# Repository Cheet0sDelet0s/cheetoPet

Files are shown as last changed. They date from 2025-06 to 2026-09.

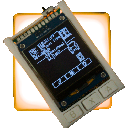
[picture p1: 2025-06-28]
photos/pixeltop.png

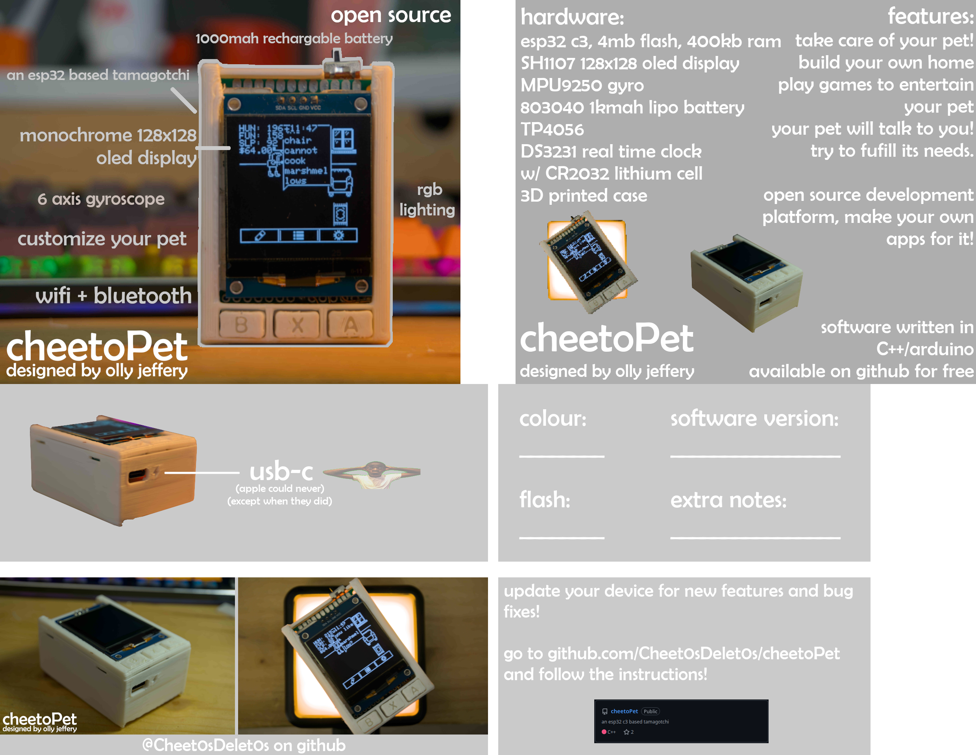
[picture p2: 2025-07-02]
photos/box.png

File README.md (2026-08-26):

<h2 align="center"><u>cheetoPet</u></h2>

**an esp32 s3 based virtual pet**
<h4 align="center"> an esp32 s3 based virtual pet </h4>

<p align="center">
    
    
<br>
    
    
</p>

### [+] notice
cheetoPet is being completely rebuilt. the pcb and software is still not finished. please star this project and come back to it later!

### [+] description
cheetoPet is a fully open-source modern tamagotchi. it features a 240*280 colour display, 3 face buttons + side rocker, 6 axis gyro and a speaker, all built on a custom pcb.

### [+] software
the software uses an abstraction layer that allows it to be ran on both esp32 and PC, where drivers for different devices can be easily created and swapped in. for PC, a lot of hardware that is present on the cheetoPet board is simulated, such as the gyro and battery. this is so the program runs as close to how it would natively. this is mostly to make development far easier, as constantly having to build the program and wait for it to upload to your esp32 takes a significant amount of time. being able to build and run it locally, while having access to regular c++ debugging tools, makes everything much less annoying.

### [+] building for pc
use the build.sh bash script in cheetoPet-V2:
`./build.sh`
you will need gcc and SDL2 installed. if the build is successful, the executable will run automatically. i develop on linux, so you may have issues if you are on windows/macos. if you are - why? without sounding like an annoying arch user (which i am), linux is simply better.

### [+] uploading to esp32
arduino IDE/CLI or the arduino vscode extension (what i use) is required to build and upload to the board. install the esp32 core in board manager, select esp32s3 dev module as your device, enable USB CDC on boot in tools and upload.

### [+] ordering pcb
i use JLCPCB for all my pcbs. they are simply the cheapest option available, but you can use any service really. just upload the gerbers and probably order a stencil to go with it. no specific board settings are needed really, though you may want to get a lower board thickness.

### [+] ordering parts
LCSC (sister company of jlcpcb)  is where i get my parts for this boardd. aliexpress unfortunately doesnt really work here. its a sad day for us all. there is a BOM you can upload however there are most likely a few parts on it that are out of stock. finding alternatives is fairly easy.

you must buy the battery and display separately. a 1S 1000mah lipo/ion is what the board expects. the display is a very specific ST7789 from BuyDisplay, you can find it on aliexpress thank GOD. https://www.aliexpress.com/item/1005008850313883.html
they are about $5-6 each.

### [+] ordering pcba
i probably wouldnt even bother assembling by hand like i did, however getting it assembled for you is just so expensive for low quantity orders. jlcpcb quoted me £150 ($200, not including battery and display cost) for 2 boards, when building 4 by hand costs £100. so unless you are ordering 1000 units, you are kind of screwed either way 🥰🥰🥰

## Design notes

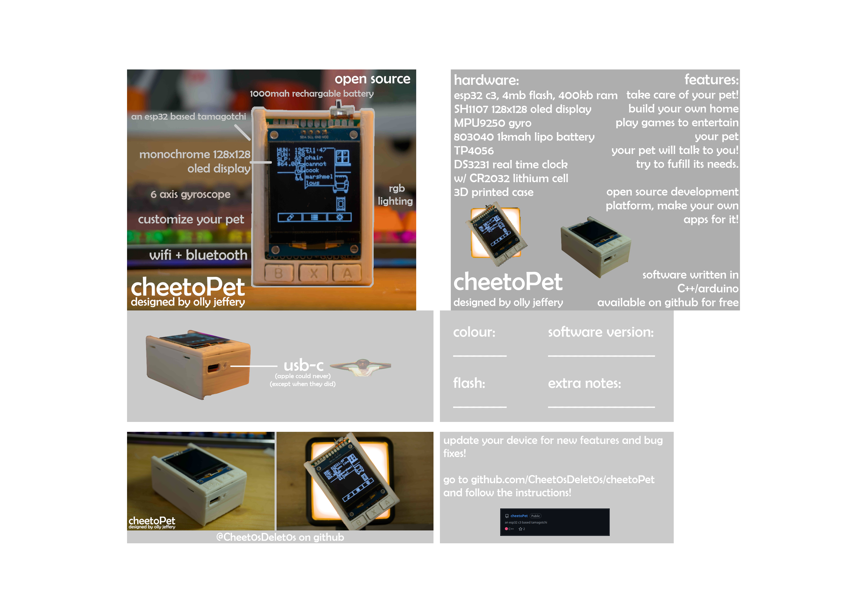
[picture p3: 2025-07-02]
photos/box2.png

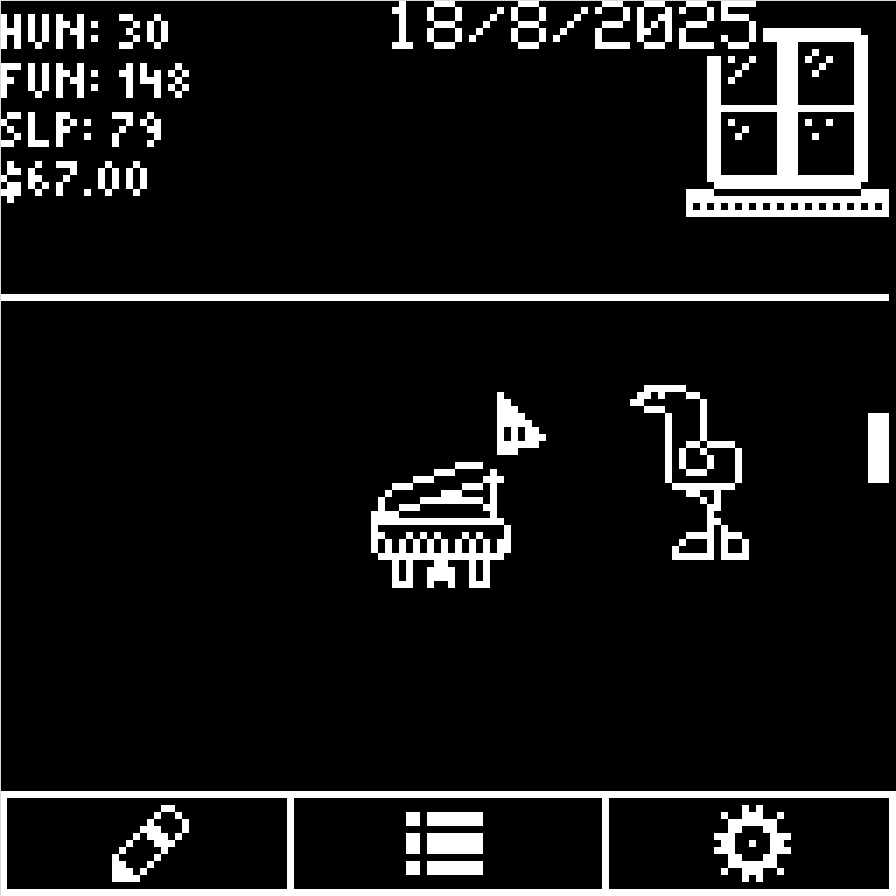
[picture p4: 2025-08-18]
photos/screenshot1.png

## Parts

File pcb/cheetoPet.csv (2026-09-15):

Reference | Qty | Value | LCSC Part Number | Exclude from BOM | Footprint
BUZZER1 | 1 | CPT-9019A-SMT-TR | C20181991 |  | EasyEDA:BUZ-SMD_L9.0-W9.0_CPT-9019A-SMT-TR
C1,C5,C6,C7,C15,C16,C17,C18,C19,C21,C24,C25,C26,C29,C31,C32,C33 | 17 | 100nF | C5137467 |  | customs:C_0805_2012Metric - CUSTOM TEXT
C2,C3,C8,C9,C20 | 5 | 10uF | C15850 |  | customs:C_0805_2012Metric - CUSTOM TEXT
C4,C30 | 2 | 1uF | C28323 |  | customs:C_0805_2012Metric - CUSTOM TEXT
C10,C14,C22,C23,C27,C28 | 6 | 22uF | C98190 |  | customs:C_0805_2012Metric - CUSTOM TEXT
CN2 | 1 | S2B-ZR-SM2-TF | C594994 |  | EasyEDA:CONN-SMD_2P-P1.50_S2B-ZR-SM2-TF-LF-SN
F1 | 1 | 1A | C2649901 |  | Fuse:Fuse_1812_4532Metric
H1,H2 | 2 | HX PZ2.54-1X5P WT | C46061678 |  | EasyEDA:HDR-SMD_5P-P2.54-H-M-W12.8-N
J2 | 1 | USB_C_Receptacle_USB2.0_16P | C2988369 |  | Connector_USB:USB_C_Receptacle_G-Switch_GT-USB-7010ASV
L1 | 1 | 0.47uH <30mOhm >4A | C42455362 |  | EasyEDA:L1008
Q1 | 1 | FS8205A | C908265 |  | footprints:SOT-23-6L_TCP
Q2 | 1 | BSS138 | C7420339 |  | Package_TO_SOT_SMD:SOT-23
R1 | 1 | 100R | C105577 |  | customs:R_0805_2012Metric - CUSTOM TEXT
R2 | 1 | 1k | C2907232 |  | customs:R_0805_2012Metric - CUSTOM TEXT
R3,R4 | 2 | 5k1 | C27834 |  | customs:R_0805_2012Metric - CUSTOM TEXT
R5,R8,R12,R15,R16,R17,R18,R22,R23,R24,R25,R26,R27,R31,R32,R35,R38 | 17 | 10k | C2907219 |  | customs:R_0805_2012Metric - CUSTOM TEXT
R7 | 1 | 1k5 | C2907216 |  | customs:R_0805_2012Metric - CUSTOM TEXT
R9 | 1 | 1k1 | C2933286 |  | customs:R_0805_2012Metric - CUSTOM TEXT
R10 | 1 | 2.94k | C865383 |  | customs:R_0805_2012Metric - CUSTOM TEXT
R11 | 1 | 18k | C17506 |  | customs:R_0805_2012Metric - CUSTOM TEXT
R19,R20 | 2 | 4k7 | C2907264 |  | customs:R_0805_2012Metric - CUSTOM TEXT
R21 | 1 | 10 | C2907220 |  | customs:R_0805_2012Metric - CUSTOM TEXT
R28,R29,R30,R33,R34,R39,R40 | 7 | 22 | C2907310 |  | customs:R_0805_2012Metric - CUSTOM TEXT
R36 | 1 | 511k | C5159719 |  | customs:R_0805_2012Metric - CUSTOM TEXT
R37 | 1 | 91k | C2933509 |  | customs:R_0805_2012Metric - CUSTOM TEXT
SW1,SW2,SW3,SW4 | 4 | BTN | C221692 |  | EasyEDA:KEY-SMD_4P-L4.2-W2.8-P1.60-LS4.6
SW5 | 1 | TS24CA | C393942 |  | EasyEDA:SW-SMD_2P-TS24CA
U1 | 1 | USBLC6-2SC6 | C5180249 |  | Package_TO_SOT_SMD:SOT-23-6
U2 | 1 | HX PM2.54-1X5P WT | C46061769 |  | EasyEDA:HDR-SMD_5P-P2.54-H-F
U3 | 1 | DW01A | C42380662 |  | Package_TO_SOT_SMD:SOT-23-6
U4 | 1 | BQ24074RGT | C54313 |  | Package_DFN_QFN:VQFN-16-1EP_3x3mm_P0.5mm_EP1.6x1.6mm
U5 | 1 | MAX17048G_T10 | C2682616 |  | Package_DFN_QFN:TDFN-8-1EP_2x2mm_P0.5mm_EP0.8x1.2mm
U6 | 1 | LSM6DSL | C126672 |  | Package_LGA:LGA-14_3x2.5mm_P0.5mm_LayoutBorder3x4y
U7 | 1 | PCF8523T/1,118 | C2651516 |  | EasyEDA:SOP-8_L4.9-W3.9-P1.27-LS6.0-BL
U8 | 1 | ESP32-S3-MINI-1U | C2980299 |  | RF_Module:ESP32-S2-MINI-1U
U9 | 1 | WS-003DB | C46598198 |  | EasyEDA:SW-SMD_WS-003DB
U10 | 1 | TPS63802DLAR | C2845237 |  | EasyEDA:VSON-10_L3.0-W2.0-P0.50-TL
U11,U13,U14 | 3 | AT24C32M/TR | C2688466 |  | EasyEDA:SOP-8_L4.9-W3.9-P1.27-LS6.0-BL
U12 | 1 | LTC2955CDDB-1#TRPBF | C683788 |  | EasyEDA:DFN-10_L3.0-W2.0-P0.50-BL-EP
X1 | 1 | SC-32S32.768kHz20PPM7pF | C97604 |  | EasyEDA:OSC-SMD_L3.2-W1.5

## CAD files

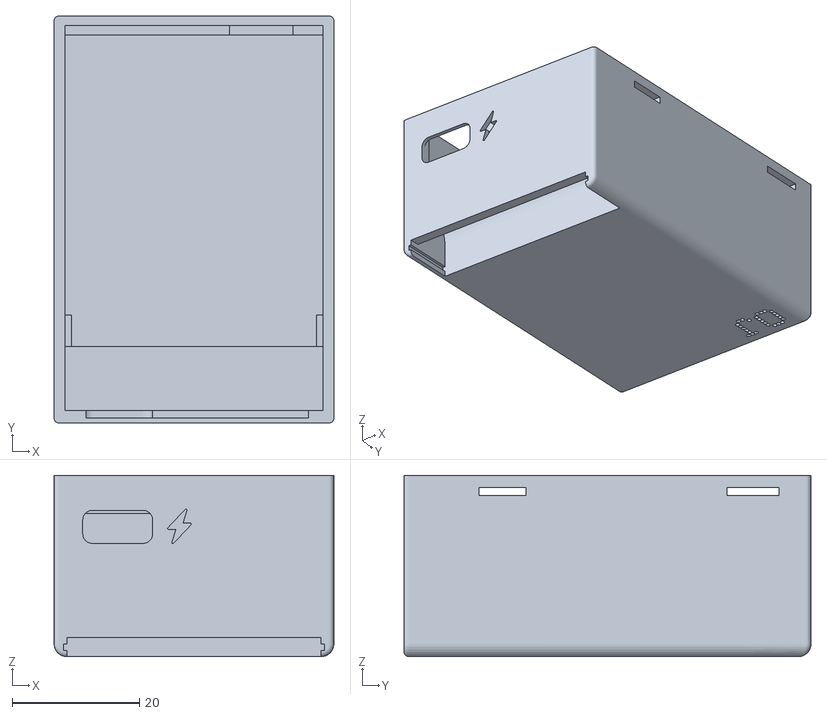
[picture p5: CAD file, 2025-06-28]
stls/body.stl
44.0 x 64.0 x 28.5

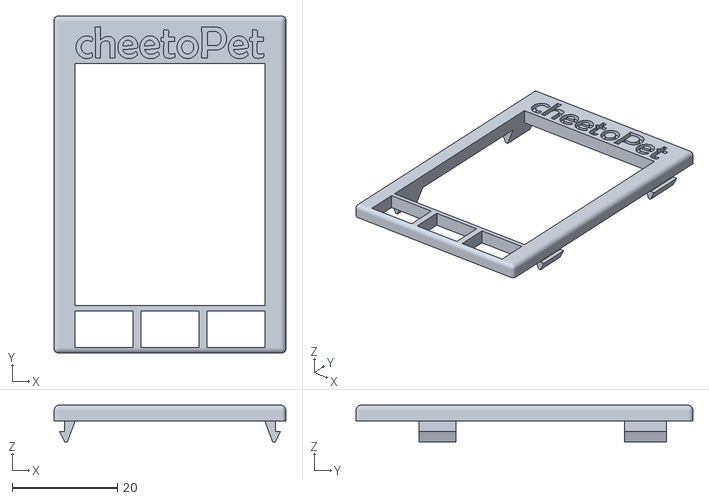
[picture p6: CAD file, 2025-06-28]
stls/faceplate.stl
44.0 x 64.0 x 7.00

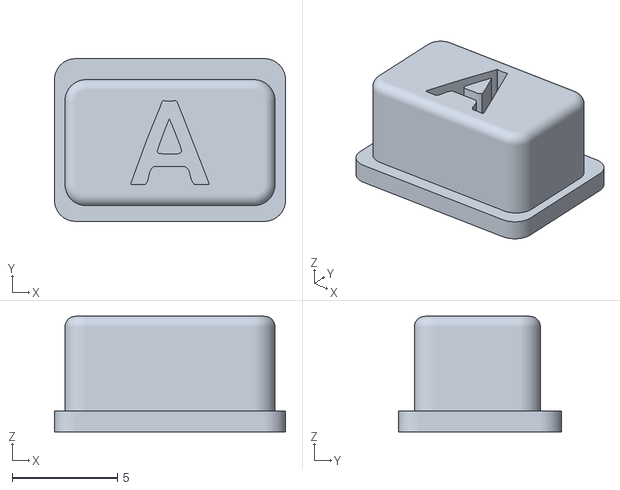
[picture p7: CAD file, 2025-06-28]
stls/A.stl
11.0 x 7.75 x 5.50

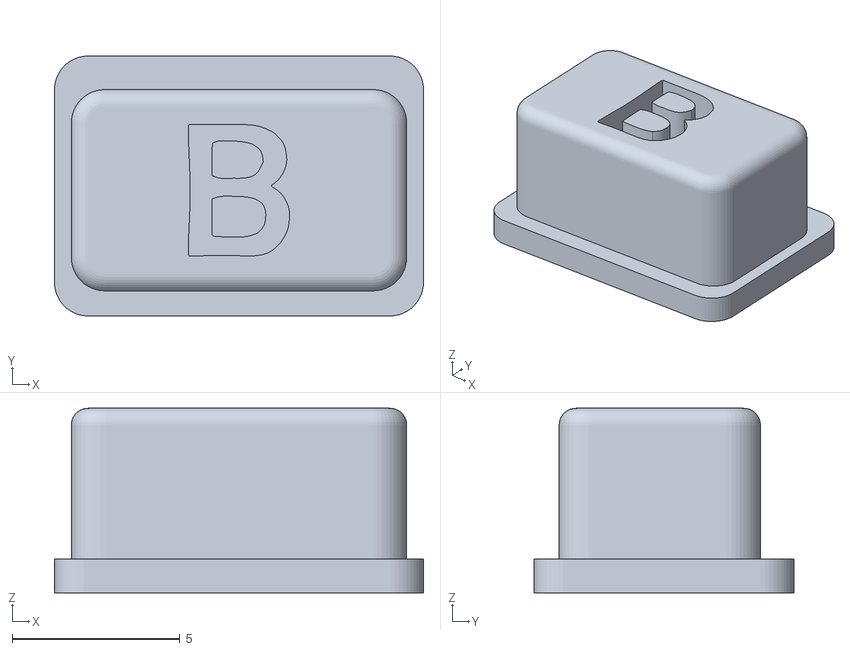
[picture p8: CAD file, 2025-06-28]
stls/B.stl
11.0 x 7.75 x 5.50

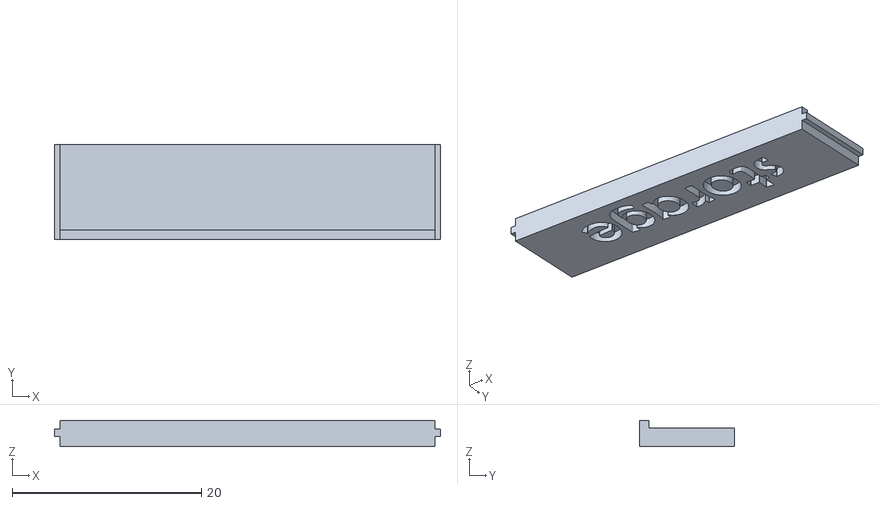
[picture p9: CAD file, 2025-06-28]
stls/manual plate.stl
40.8 x 10.0 x 2.80

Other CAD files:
stls/X.stl
legacy/stls/X.stl

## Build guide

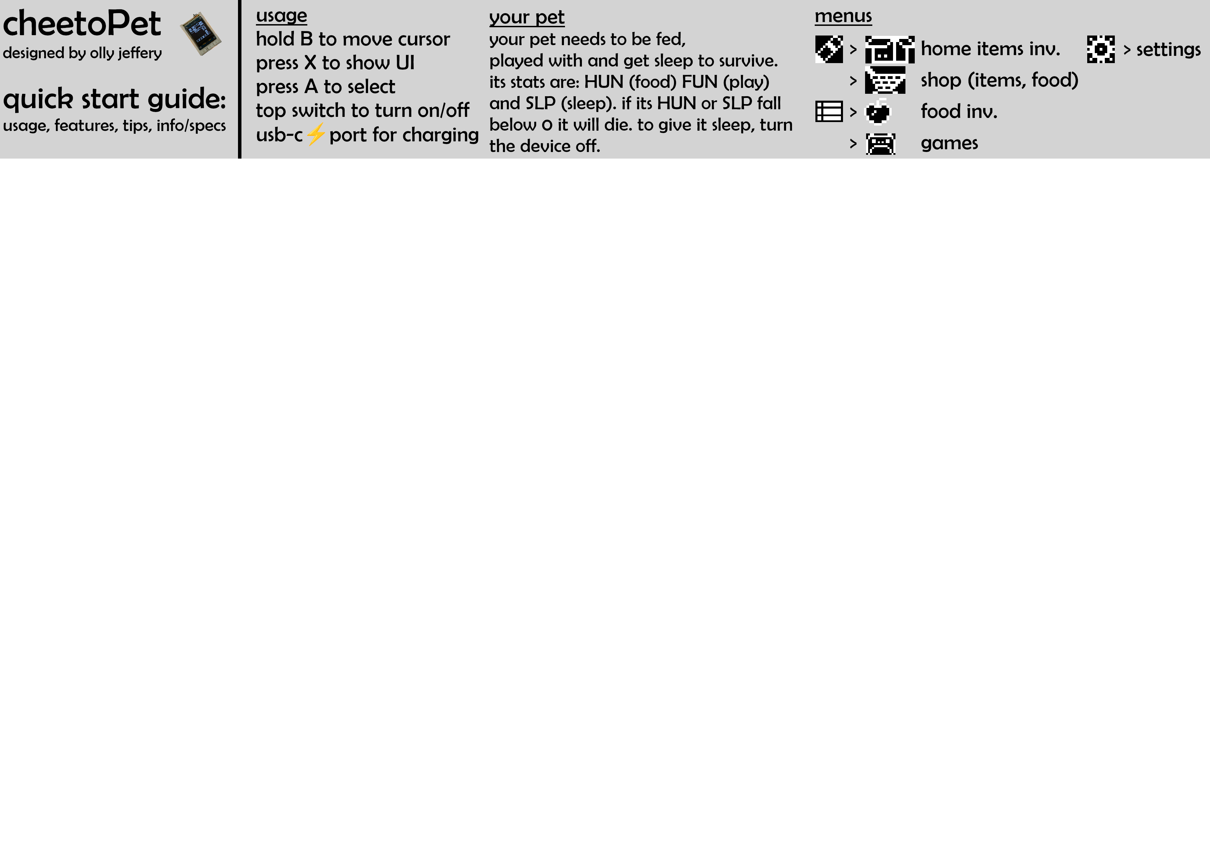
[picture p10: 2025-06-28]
photos/quick start guide.png

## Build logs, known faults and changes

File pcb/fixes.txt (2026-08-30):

FIXES NEEDED FOR PCB:

X button pulls the pin low, it should pull it high - DONE
vias under esp32 chip should probably be moved away to improve durability

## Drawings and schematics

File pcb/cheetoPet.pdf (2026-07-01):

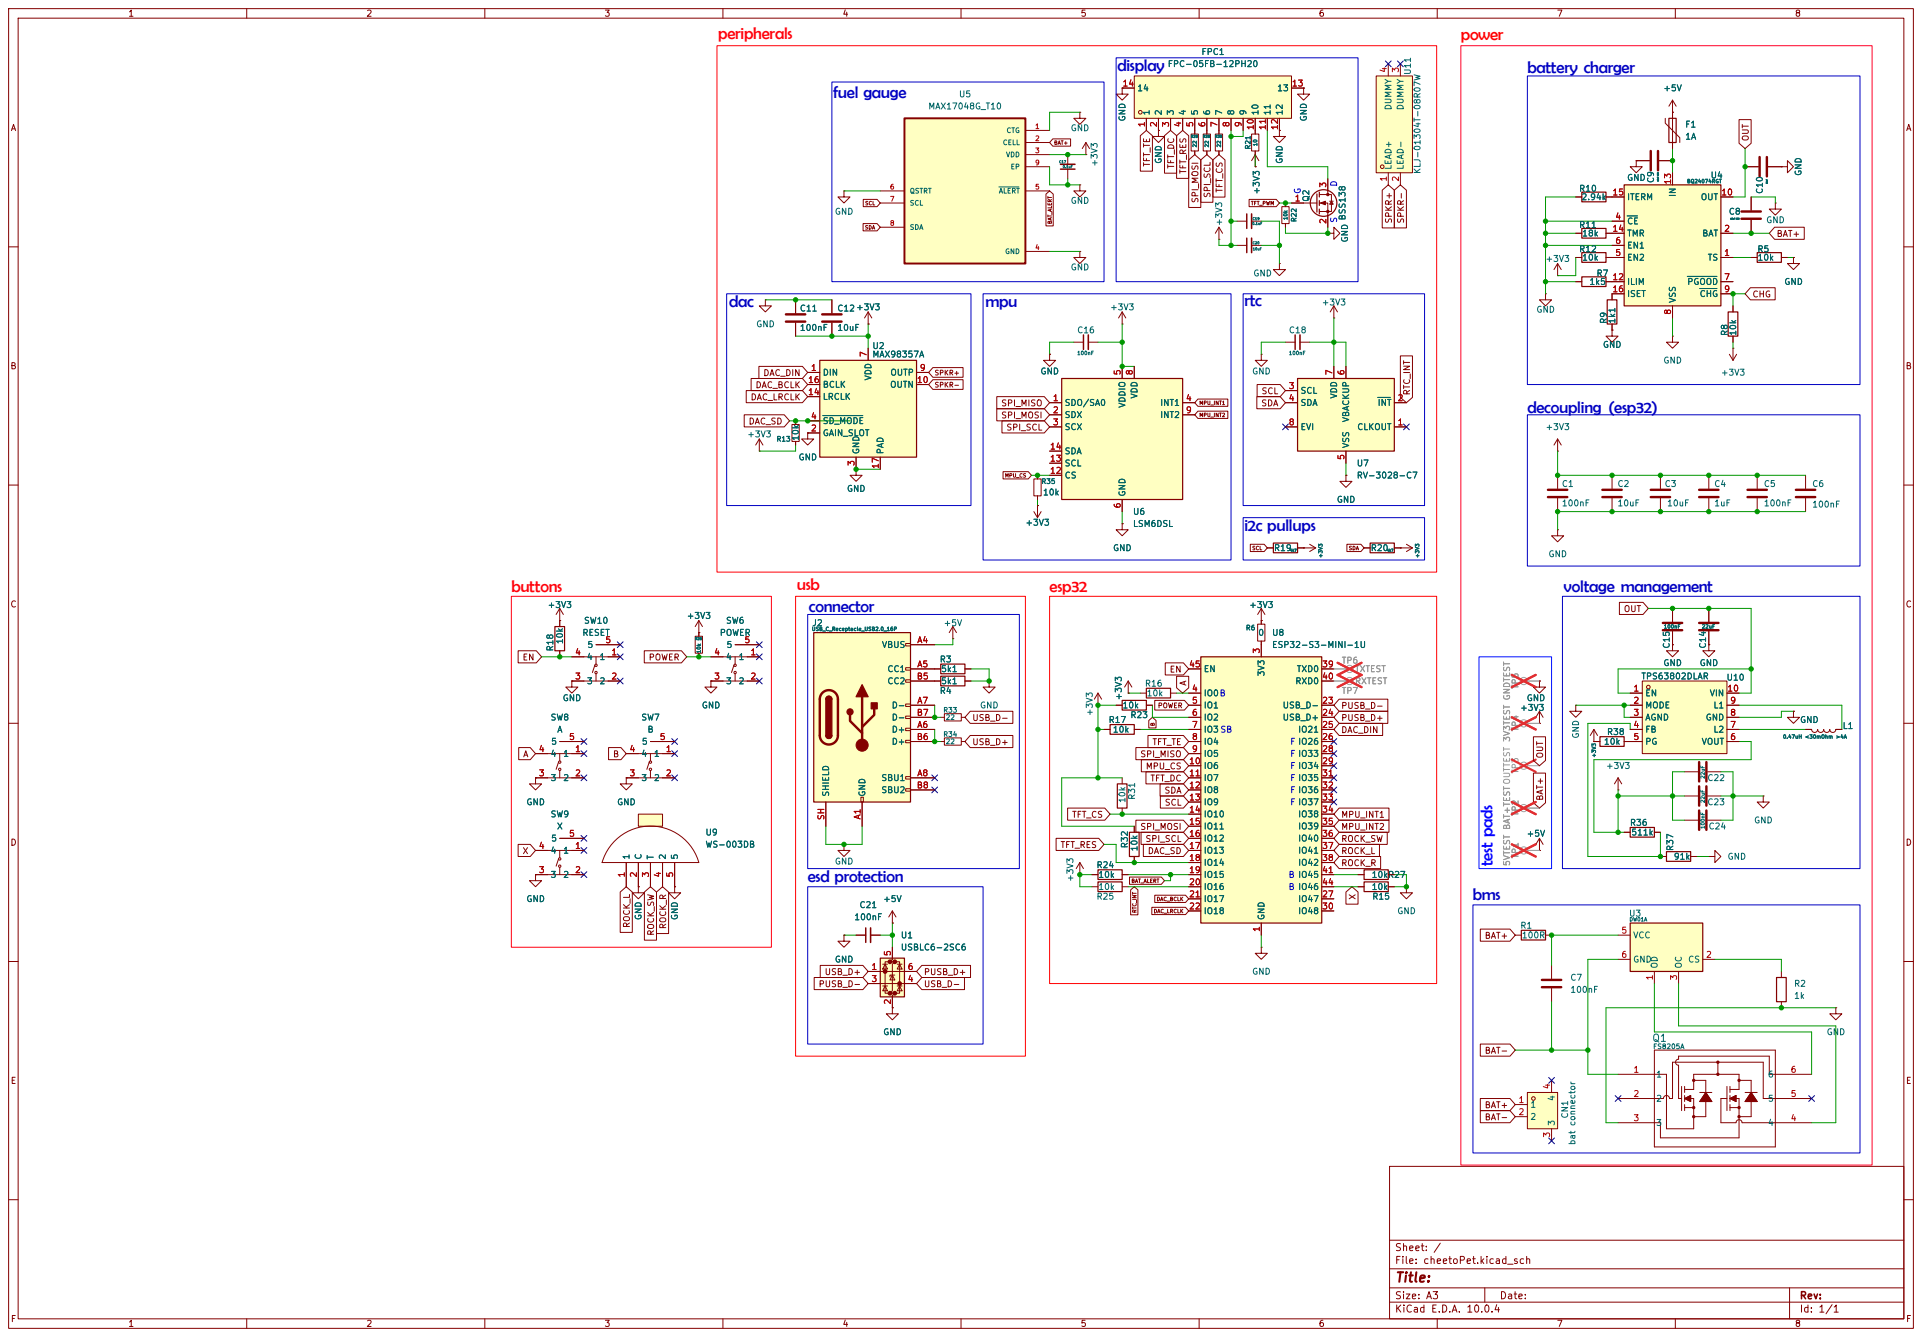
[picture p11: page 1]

TMR 14

Size: A3 | Rev:
KiCad E.D.A. 10.0.4 | Id: 1/1

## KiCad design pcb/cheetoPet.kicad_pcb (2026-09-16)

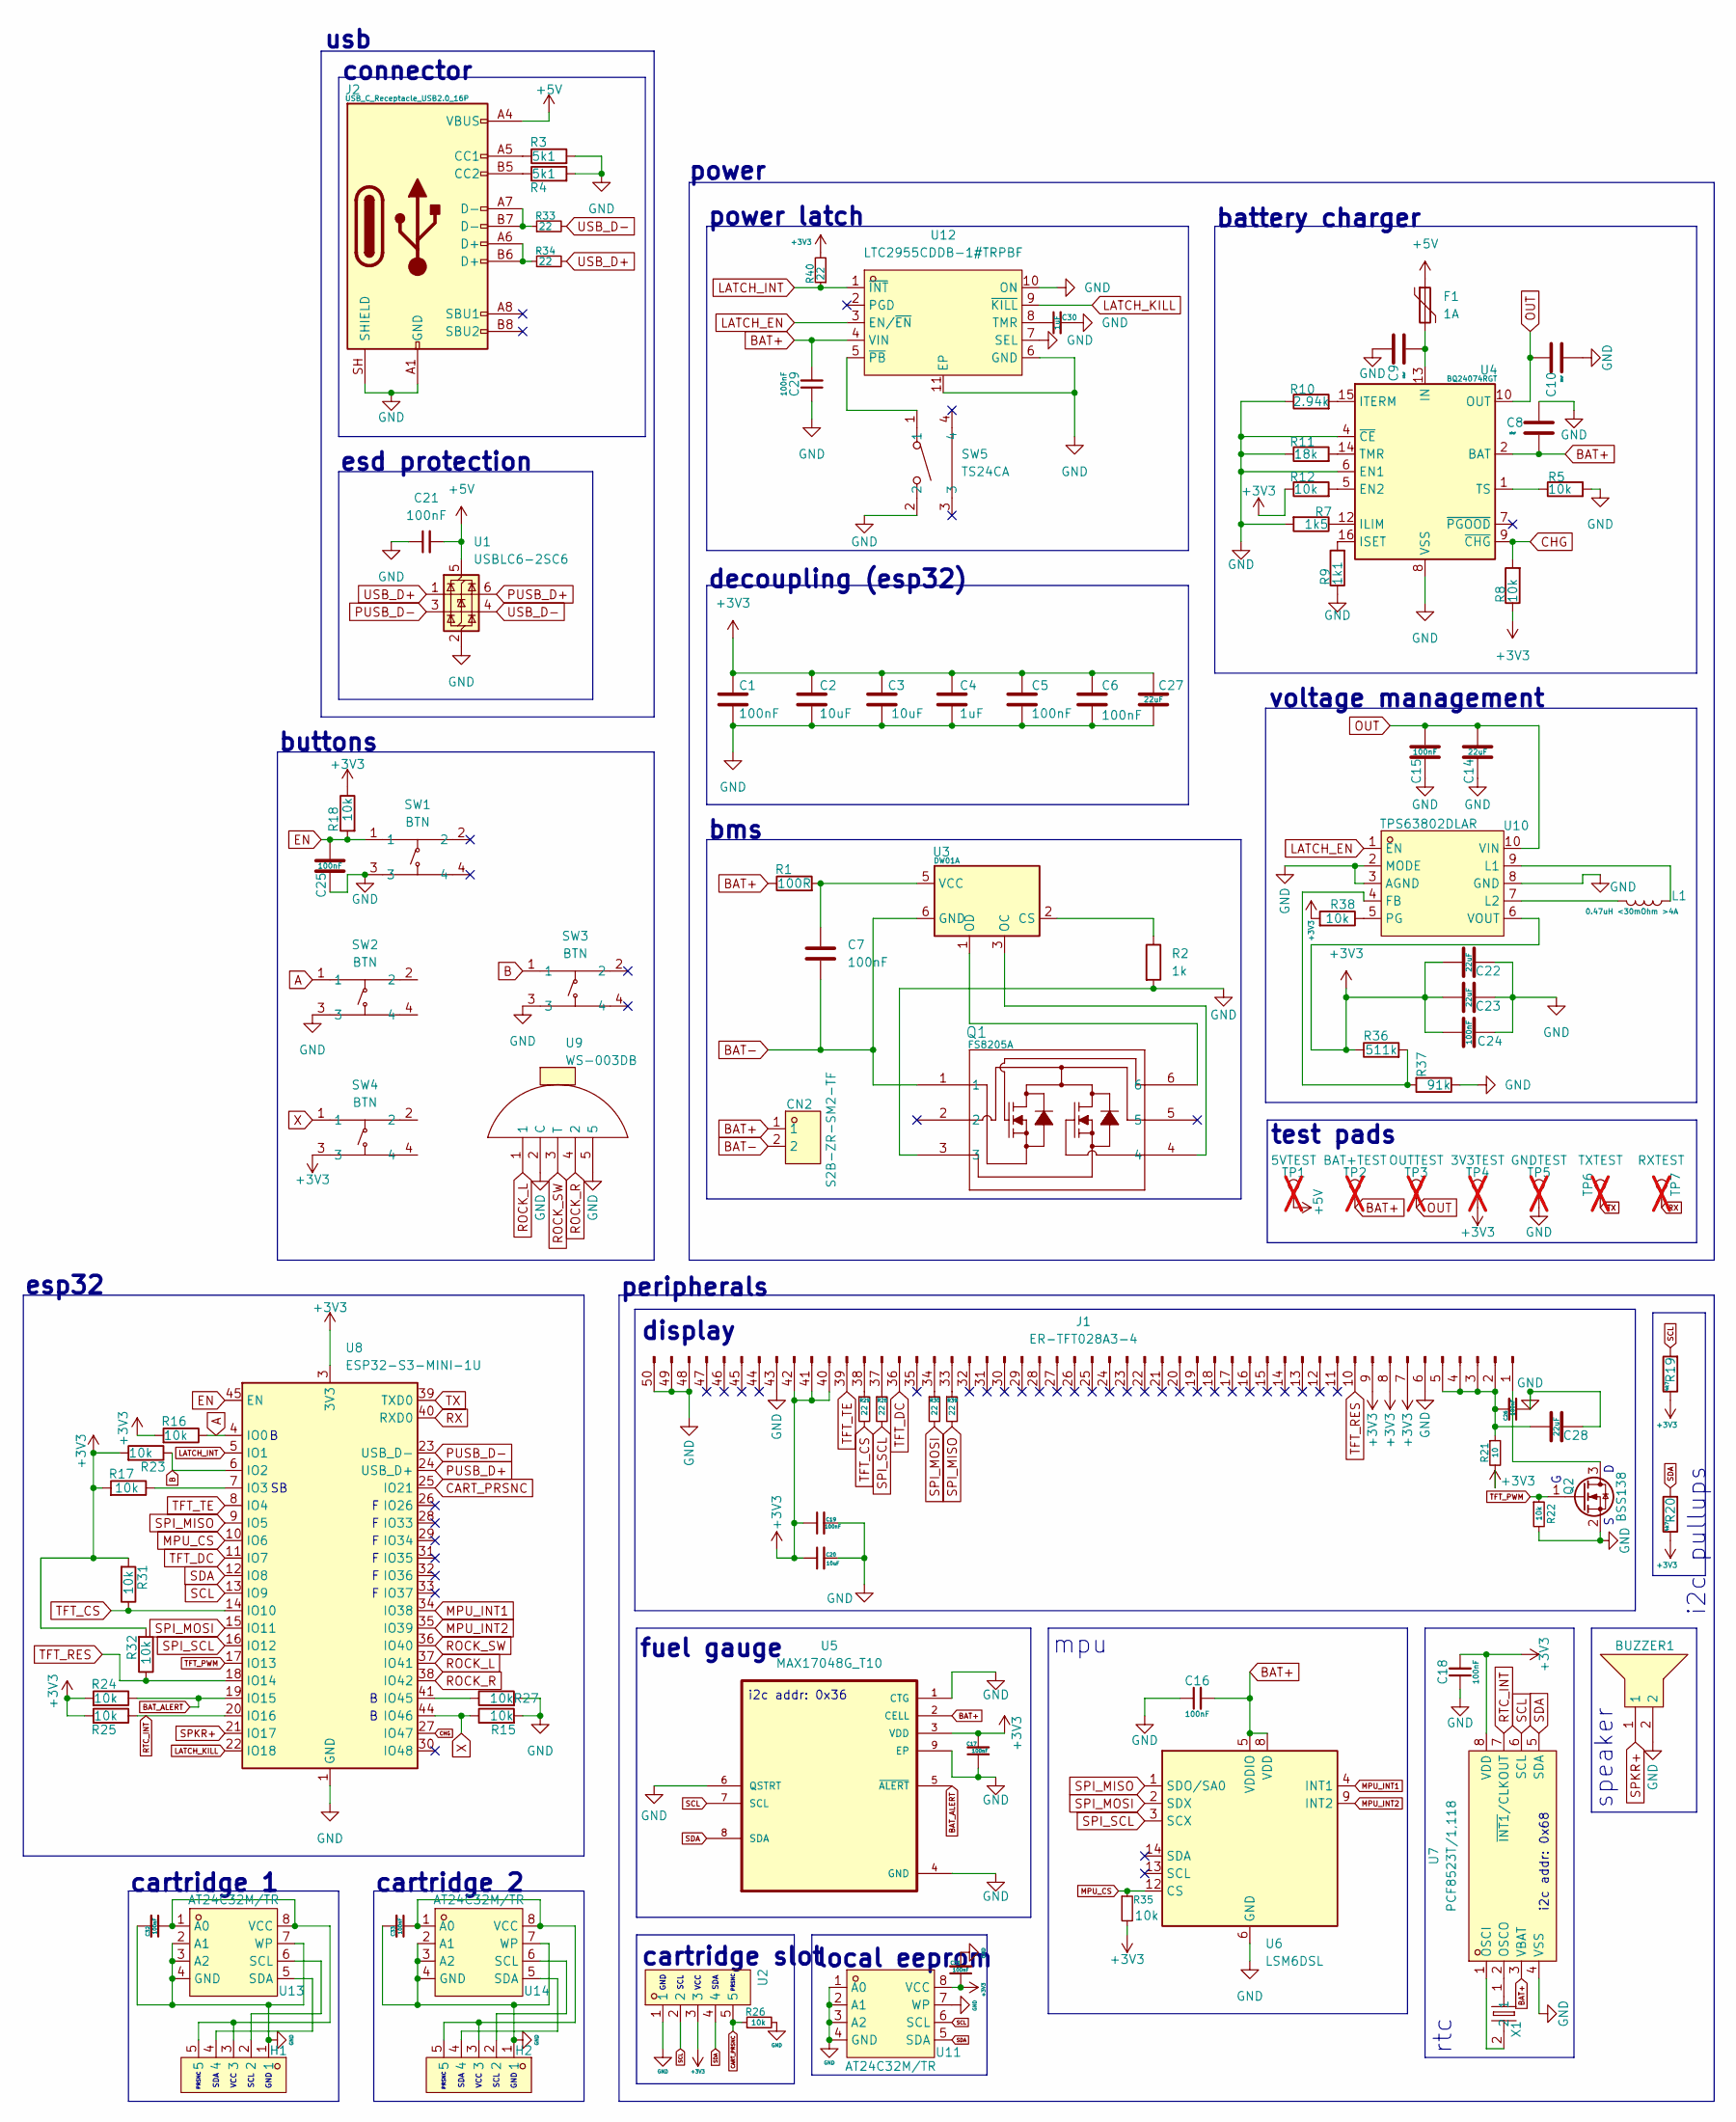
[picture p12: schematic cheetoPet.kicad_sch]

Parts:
BUZZER1: CPT-9019A-SMT-TR; BUZ-SMD_L9.0-W9.0_CPT-9019A-SMT-TR; MPN CPT-9019A-SMT-TR; LCSC Part C20181991
C1, C5, C6, C7, C15, C16, C17, C18, C19, C21, C24, C25, C26, C29, C31, C32, C33: 100nF; C_0805_2012Metric - CUSTOM TEXT; LCSC Part C5137467
C2, C3, C8, C9, C20: 10uF; C_0805_2012Metric - CUSTOM TEXT; LCSC Part C15850
C4, C30: 1uF; C_0805_2012Metric - CUSTOM TEXT; LCSC Part C28323
C10, C14, C22, C23, C27, C28: 22uF; C_0805_2012Metric - CUSTOM TEXT; LCSC Part C98190
CN2: S2B-ZR-SM2-TF; CONN-SMD_2P-P1.50_S2B-ZR-SM2-TF-LF-SN; MPN S2B-ZR-SM2-TF(LF)(SN); LCSC Part C594994
F1: 1A; Fuse_1812_4532Metric; LCSC Part C2649901
H1, H2: HX PZ2.54-1X5P WT; HDR-SMD_5P-P2.54-H-M-W12.8-N; MPN HX PZ2.54-1x5P WT; LCSC Part C46061678
J1: ER-TFT028A3-4; FPC-50pin,0.5Pitch
J2: USB_C_Receptacle_USB2.0_16P; USB_C_Receptacle_G-Switch_GT-USB-7010ASV; LCSC Part C2988369
L1: 0.47uH <30mOhm >4A; L1008; LCSC Part C42455362
Q1: FS8205A; SOT-23-6L_TCP; LCSC Part C908265
Q2: BSS138; SOT-23; LCSC Part C7420339
R1: 100R; R_0805_2012Metric - CUSTOM TEXT; LCSC Part C105577
R2: 1k; R_0805_2012Metric - CUSTOM TEXT; LCSC Part C2907232
R3, R4: 5k1; R_0805_2012Metric - CUSTOM TEXT; LCSC Part C27834
R5, R8, R12, R15, R16, R17, R18, R22, R23, R24, R25, R26, R27, R31, R32, R35, R38: 10k; R_0805_2012Metric - CUSTOM TEXT; LCSC Part C2907219
R7: 1k5; R_0805_2012Metric - CUSTOM TEXT; LCSC Part C2907216
R9: 1k1; R_0805_2012Metric - CUSTOM TEXT; LCSC Part C2933286
R10: 2.94k; R_0805_2012Metric - CUSTOM TEXT; LCSC Part C865383
R11: 18k; R_0805_2012Metric - CUSTOM TEXT; LCSC Part C17506
R19, R20: 4k7; R_0805_2012Metric - CUSTOM TEXT; LCSC Part C2907264
R21: 10; R_0805_2012Metric - CUSTOM TEXT; LCSC Part C2907220
R28, R29, R30, R33, R34, R39, R40: 22; R_0805_2012Metric - CUSTOM TEXT; LCSC Part C2907310
R36: 511k; R_0805_2012Metric - CUSTOM TEXT; LCSC Part C5159719
R37: 91k; R_0805_2012Metric - CUSTOM TEXT; LCSC Part C2933509
SW1, SW2, SW3, SW4: BTN; KEY-SMD_4P-L4.2-W2.8-P1.60-LS4.6; MPN KMR621NGLFS; LCSC Part C221692
SW5: TS24CA; SW-SMD_2P-TS24CA; MPN TS24CA; LCSC Part C393942
TP1: 5VTEST; TestPoint_Pad_1.5x1.5mm; not fitted
TP2: BAT+TEST; TestPoint_Pad_1.5x1.5mm; not fitted
TP3: OUTTEST; TestPoint_Pad_1.5x1.5mm; not fitted
TP4: 3V3TEST; TestPoint_Pad_1.5x1.5mm; not fitted
TP5: GNDTEST; TestPoint_Pad_1.5x1.5mm; not fitted
TP6: TXTEST; TestPoint_Pad_1.5x1.5mm; not fitted
TP7: RXTEST; TestPoint_Pad_1.5x1.5mm; not fitted
U1: USBLC6-2SC6; SOT-23-6; LCSC Part C5180249
U2: HX PM2.54-1X5P WT; HDR-SMD_5P-P2.54-H-F; MPN HX PM2.54-1x5P WT; LCSC Part C46061769
U3: DW01A; SOT-23-6; LCSC Part C42380662
U4: BQ24074RGT; VQFN-16-1EP_3x3mm_P0.5mm_EP1.6x1.6mm; LCSC Part C54313
U5: MAX17048G_T10; TDFN-8-1EP_2x2mm_P0.5mm_EP0.8x1.2mm; LCSC Part C2682616
U6: LSM6DSL; LGA-14_3x2.5mm_P0.5mm_LayoutBorder3x4y; LCSC Part C126672
U7: PCF8523T/1,118; SOP-8_L4.9-W3.9-P1.27-LS6.0-BL; MPN PCF8523T/1,118; LCSC Part C2651516
U8: ESP32-S3-MINI-1U; ESP32-S2-MINI-1U; LCSC Part C2980299
U9: WS-003DB; SW-SMD_WS-003DB; MPN WS-003DB; LCSC Part C46598198
U10: TPS63802DLAR; VSON-10_L3.0-W2.0-P0.50-TL; MPN TPS63802DLAR; LCSC Part C2845237
U11, U13, U14: AT24C32M/TR; SOP-8_L4.9-W3.9-P1.27-LS6.0-BL; MPN AT24C32M/TR; LCSC Part C2688466
U12: LTC2955CDDB-1#TRPBF; DFN-10_L3.0-W2.0-P0.50-BL-EP; MPN LTC2955CDDB-1#TRPBF; LCSC Part C683788
X1: SC-32S32.768kHz20PPM7pF; OSC-SMD_L3.2-W1.5; MPN SC-32S32.768kHz20PPM7pF; LCSC Part C97604

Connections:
+3V3: C1.1, C2.1, C3.1, C4.1, C5.1, C6.1, C17.2, C18.2, C19.1, C20.1, C22.1, C23.1, C24.1, C27.2, C31.1, J1.7, J1.8, J1.9, J1.40, J1.41, J1.42, R8.1, R12.1, R16.2, R17.2, R18.1, R19.1, R20.1, R21.2, R23.2, R24.2, R25.2, R31.2, R32.2, R35.2, R36.1, R38.2, R40.2, SW4.3, TP4.1 (1_1), U2.3, U5.3 (VDD), U7.8 (VDD), U8.3 (3V3), U10.6 (VOUT), U11.8 (VCC)
+5V: C21.2, F1.1, J2.A4 (VBUS), J2.A9 (VBUS), J2.B4 (VBUS), J2.B9 (VBUS), TP1.1 (1_1), U1.5 (VBUS)
A: R16.1, SW2.1, U8.4 (IO0)
B: R23.1, SW3.1, U8.6 (IO2)
BAT+: C8.2, C16.2, C29.2, CN2.1, R1.1, TP2.1 (1_1), U4.2 (BAT), U4.3 (BAT), U5.2 (CELL), U6.5 (VDDIO), U6.8 (VDD), U7.3 (VBAT), U12.4 (VIN)
BAT-: C7.2, CN2.2, Q1.1, U3.6 (GND)
BAT_ALERT: R24.1, U5.5 (~ALERT), U8.19 (IO15)
CART_PRSNC: R26.1, U2.5, U8.25 (IO21)
CHG: R8.2, U4.9 (~CHG), U8.27 (IO47)
EN: C25.1, R18.2, SW1.1, U8.45 (EN)
GND: BUZZER1.2, C1.2, C2.2, C3.2, C4.2, C5.2, C6.2, C8.1, C9.1, C10.2, C14.2, C15.2, C16.1, C17.1, C18.1, C19.2, C20.2, C21.1, C22.2, C23.2, C24.2, C25.2, C26.1, C27.1, C28.2, C29.1, C30.2, C31.2, C32.2, C33.2, H1.1, H2.1, J1.6, J1.43, J1.48, J1.49, J1.50, J2.A1 (GND), J2.A12 (GND), J2.B1 (GND), J2.B12 (GND), J2.SH (SHIELD), Q1.3, Q2.2 (S), R2.2, R3.2, R4.2, R5.2, R7.2, R9.1, R10.1, R11.1, R15.2, R22.2, R26.2, R27.2, R37.1, SW1.3, SW2.3, SW3.3, SW5.2, TP5.1 (1_1), U1.2 (GND), U2.1, U4.4 (~CE), U4.6 (EN1), U4.8 (VSS), U4.17 (VSS), U5.1 (CTG), U5.4 (GND), U5.6 (QSTRT), U5.9 (EP), U6.6 (GND), U6.7 (GND), U7.4 (VSS), U8.1 (GND), U8.2 (GND), U8.42 (GND), U8.43 (GND), U8.46 (GND), U8.47 (GND), U8.48 (GND), U8.49 (GND), U8.50 (GND), U8.51 (GND), U8.52 (GND), U8.53 (GND), U8.54 (GND), U8.55 (GND), U8.56 (GND), U8.57 (GND), U8.58 (GND), U8.59 (GND), U8.60 (GND), U8.61 (GND), U8.62 (GND), U8.63 (GND), U8.64 (GND), U8.65 (GND), U9.2 (C), U9.5, U10.2 (MODE), U10.3 (AGND), U10.8 (GND), U11.1 (A0), U11.2 (A1), U11.3 (A2), U11.4 (GND), U11.7 (WP), U12.6 (GND), U12.7 (SEL), U12.10 (ON), U12.11 (EP), U13.2 (A1), U13.3 (A2), U13.4 (GND), U13.7 (WP), U14.2 (A1), U14.3 (A2), U14.4 (GND), U14.7 (WP)
LATCH_EN: U10.1 (EN), U12.3 (EN/~EN)
LATCH_INT: R40.1, U8.5 (IO1), U12.1 (~INT)
LATCH_KILL: U8.22 (IO18), U12.9 (~KILL)
MPU_CS: R35.1, U6.12 (CS), U8.10 (IO6)
MPU_INT1: U6.4 (INT1), U8.34 (IO38)
MPU_INT2: U6.9 (INT2), U8.35 (IO39)
unnamed: J1.1, Q2.3 (D)
unnamed: C26.2, C28.1, J1.2, J1.3, J1.4, J1.5, R21.1
unnamed: J1.33, R39.1
unnamed: J1.34, R30.1
unnamed: J1.37, R28.1
unnamed: J1.38, R29.1
unnamed: J2.A5 (CC1), R3.1
unnamed: J2.B5 (CC2), R4.1
unnamed: J2.A6 (D+), J2.B6 (D+), R34.1
unnamed: J2.A7 (D-), J2.B7 (D-), R33.1
unnamed: R2.1, U3.2 (CS)
unnamed: Q1.4, U3.3 (OC)
unnamed: Q1.6, U3.1 (OD)
unnamed: C7.1, R1.2, U3.5 (VCC)
unnamed: R12.2, U4.5 (EN2)
unnamed: R7.1, U4.12 (ILIM)
unnamed: C9.2, F1.2, U4.13 (IN)
unnamed: R9.2, U4.16 (ISET)
unnamed: R10.2, U4.15 (ITERM)
unnamed: R11.2, U4.14 (TMR)
unnamed: R5.1, U4.1 (TS)
unnamed: U7.1 (OSCI), X1.2
unnamed: U7.2 (OSCO), X1.1
unnamed: R17.1, U8.7 (IO3)
unnamed: R27.1, U8.41 (IO45)
unnamed: R36.2, R37.2, U10.4 (FB)
unnamed: L1.2, U10.9 (L1)
unnamed: L1.1, U10.7 (L2)
unnamed: R38.1, U10.5 (PG)
unnamed: C30.1, U12.8 (TMR)
unnamed: SW5.1, U12.5 (~PB)
unnamed: C32.1, H1.3, H1.5, U13.1 (A0), U13.8 (VCC)
unnamed: H1.2, U13.6 (SCL)
unnamed: H1.4, U13.5 (SDA)
unnamed: C33.1, H2.3, H2.5, U14.1 (A0), U14.8 (VCC)
unnamed: H2.2, U14.6 (SCL)
unnamed: H2.4, U14.5 (SDA)
OUT: C10.1, C14.1, C15.1, TP3.1 (1_1), U4.10 (OUT), U4.11 (OUT), U10.10 (VIN)
PUSB_D+: U1.6 (I/O1), U8.24 (USB_D+)
PUSB_D-: U1.3 (I/O2), U8.23 (USB_D-)
ROCK_L: U8.37 (IO41), U9.1
ROCK_R: U8.38 (IO42), U9.4 (2)
ROCK_SW: U8.36 (IO40), U9.3 (T)
RTC_INT: R25.1, U7.7 (~INT1/CLKOUT), U8.20 (IO16)
RX: TP7.1 (1_1), U8.40 (RXD0)
SCL: R19.2, U2.2, U5.7 (SCL), U7.6 (SCL), U8.13 (IO9), U11.6 (SCL)
SDA: R20.2, U2.4, U5.8 (SDA), U7.5 (SDA), U8.12 (IO8), U11.5 (SDA)
SPI_MISO: R39.2, U6.1 (SDO/SA0), U8.9 (IO5)
SPI_MOSI: R30.2, U6.2 (SDX), U8.15 (IO11)
SPI_SCL: R28.2, U6.3 (SCX), U8.16 (IO12)
SPKR+: BUZZER1.1, U8.21 (IO17)
TFT_CS: R29.2, R31.1, U8.14 (IO10)
TFT_DC: J1.36, U8.11 (IO7)
TFT_PWM: Q2.1 (G), R22.1, U8.17 (IO13)
TFT_RES: J1.10, R32.1, U8.18 (IO14)
TFT_TE: J1.39, U8.8 (IO4)
TX: TP6.1 (1_1), U8.39 (TXD0)
USB_D+: R34.2, U1.1 (I/O1)
USB_D-: R33.2, U1.4 (I/O2)
X: R15.1, SW4.1, U8.44 (IO46)

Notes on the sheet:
cartridge slot
VCC
SCL
fuel gauge
peripherals
voltage management
GND
i2c pullups
display
power
speaker
SDA
usb
bms
mpu
i2c addr: 0x68
cartridge 2
esd protection
esp32
PRSNC
test pads
local eeprom
i2c addr: 0x36
connector
decoupling (esp32)
rtc
power latch
battery charger
buttons
cartridge 1

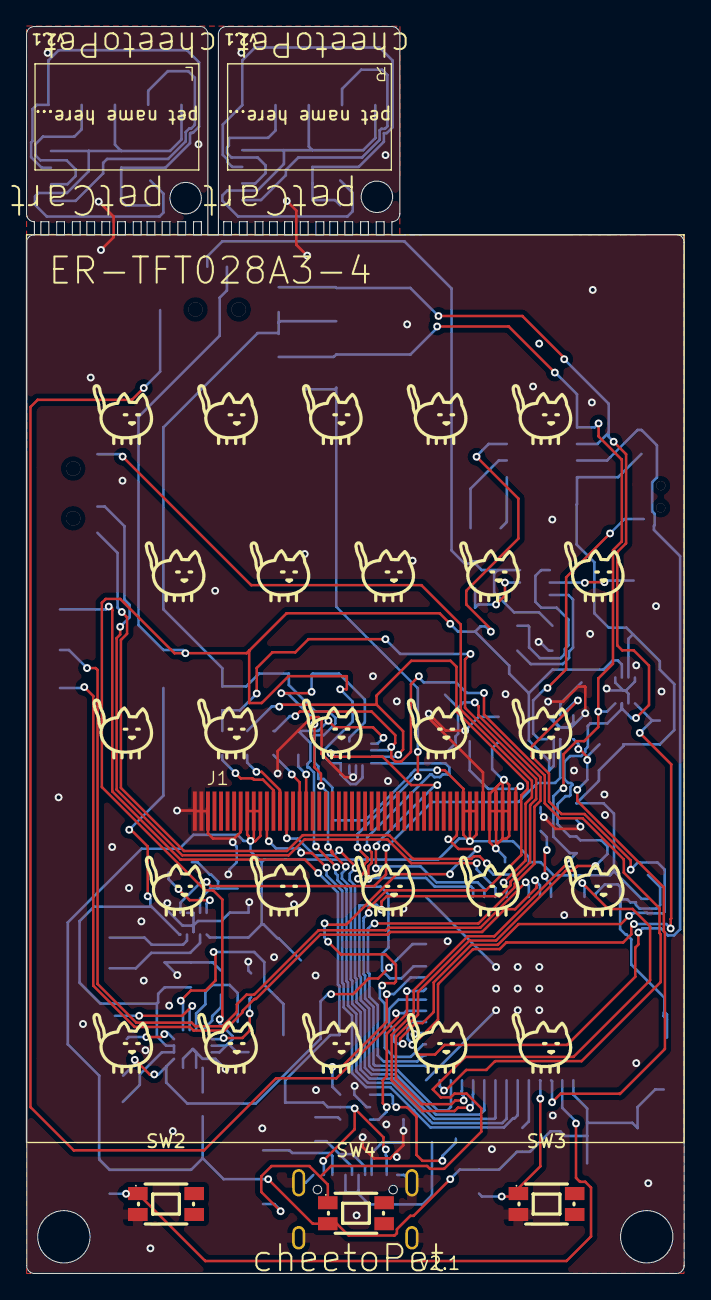
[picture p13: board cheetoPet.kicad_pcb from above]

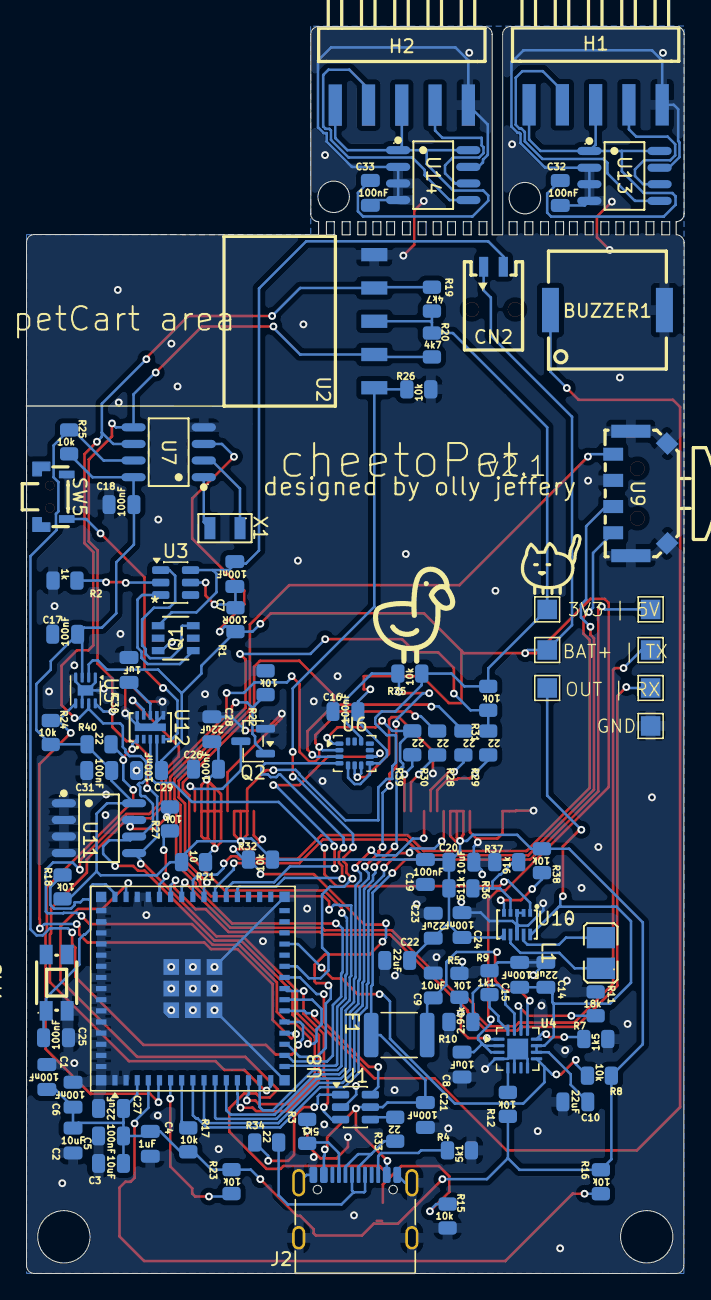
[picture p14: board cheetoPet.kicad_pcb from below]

Board: 2 copper layers, 50.2 x 95.2 mm, 104 parts (100 on the bottom side), 77 nets.

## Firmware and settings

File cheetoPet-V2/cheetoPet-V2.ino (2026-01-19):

 /***********************************\
 | cheetoPet V2 - by olly jeffery :) |
 \***********************************/

// ---- LIBRARIES ----
#include <Arduino.h>

// ---- CHEETOPET FILES ----
#include "hardware.h"
#include "os.h"

void setup() {
  initPins(); // set pinModes
  initPeripherals(); // begin serial, i2c, etc
  initDisplay(); // initialise display, clear it, set text color to white (i always forget to do this).
  batteryManagement();
  
  bootMenu(); // allow user to decide whether they want to boot into os
  // esp will sleep here if user doesnt decide to boot, will resume when power switch is toggled
  osStartup();

  beginOS(); // basically loop() equivalent
}

void loop() {
  // code will never reach loop unless something has gone terribly wrong. delay and debug here just in case
  Serial.println("CODE HAS REACHED LOOP() SOMEHOW. PROGRAM WILL DO NOTHING NOW :DD");
  display.clearDisplay();
  display.print("big boi error. code has reached loop()");
  display.display();
  delay(500);
}

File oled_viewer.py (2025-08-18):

import serial
from PIL import Image, ImageTk
import tkinter as tk

# --- CONFIG ---
PORT = "/dev/ttyACM0"        # change to your serial port (Linux ex: "/dev/ttyUSB0")
BAUD = 921600        # match your Arduino baud rate
WIDTH = 128          # your OLED width
HEIGHT = 128          # your OLED height
SCALE = 7              # how much to scale pixels in the viewer
OFFSET = 0  # pixels
# ---------------

def read_frame(ser):
    """
    Reads one ASCII frame (buffer dump) from serial and returns it as a 2D list of 0/1 pixels.
    """
    pixels = []
    while True:
        line = ser.readline().decode(errors="ignore").strip()
        if not line:
            break
        row = [1 if c == "#" else 0 for c in line]
        row = row[-OFFSET:] + row[:-OFFSET]  # rotate right by OFFSET

        # --- FIX: make sure row is exactly WIDTH long ---
        if len(row) < WIDTH:
            row += [0] * (WIDTH - len(row))   # pad missing pixels
        elif len(row) > WIDTH:
            row = row[:WIDTH]  # trim extra pixels

        pixels.append(row)

    # --- FIX: make sure we always have HEIGHT rows ---
    while len(pixels) < HEIGHT:
        pixels.append([0] * WIDTH)
    print(f"Got frame: {len(pixels)}x{len(pixels[0])}")
    return pixels


def pixels_to_image(pixels):
    h = len(pixels)
    w = len(pixels[0]) if h > 0 else 0
    img = Image.new("1", (w, h))
    for y, row in enumerate(pixels):
        for x, val in enumerate(row):
            img.putpixel((x, y), 255 if val else 0)
    return img.resize((w*SCALE, h*SCALE), Image.NEAREST)

def update():
    global imgtk
    pixels = read_frame(ser)
    print("Frame sample:", "".join("#" if p else "." for p in pixels[0][:32]))
    if pixels:
        img = pixels_to_image(pixels)
        imgtk = ImageTk.PhotoImage(img)
        canvas.create_image(0, 0, anchor="nw", image=imgtk)
    root.after(50, update)  # schedule next update

# --- Serial setup ---
ser = serial.Serial(PORT, BAUD, timeout=1)

# --- Tkinter GUI ---
root = tk.Tk()
root.title("OLED Viewer")
canvas = tk.Canvas(root, width=WIDTH*SCALE, height=HEIGHT*SCALE, bg="black")
canvas.pack()

update()
root.mainloop()

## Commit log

2025-06-14 bug fixes, pong addons, complaining about sleep, accelerometer, g force death, eeprom testing
2025-06-21 readme update, removed old battery handling stuff
2025-06-28 case stls added, photos added
    [A.stl, B.stl, X.stl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]
2025-08-15 added speaker, some changes and stuff, working on pcb
2025-08-17 added UNFINISHED pcb files
    [cheetoPet-B_Cu.gbr, cheetoPet-B_Mask.gbr, cheetoPet-B_Paste.gbr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]
2025-08-26 added cursor snapping to buttons/interaction points, bug fixes
2025-09-11 pcb updates, other stuff idfk
    [cheetoPet-B_Cu.gbr, cheetoPet-B_Mask.gbr, cheetoPet-B_Paste.gbr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]
2025-09-13 so much stuff! added particle system, new mouse toggle mode, procedual news, bug fixes, deleting items
    [newsTest.py]
2026-01-19 NEW PCB v0.3, pretty much finished, also some code changes (i think safe crack game which is rubbish)
    [cheetoPet.kicad_pcb, cheetoPet.kicad_sch]
2026-06-28 new pcb lol
    [cheetoPet-B_Cu.gbr, cheetoPet-B_Mask.gbr, cheetoPet-B_Paste.gbr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]
2026-07-01 pcb finished
    [cheetoPet-B_Cu.gbl, cheetoPet-B_Mask.gbs, cheetoPet-B_Paste.gbp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]
2026-08-23 started writing compatibility layer for esp32 and PC, almost lost this code at a boat dock
    [A.stl, B.stl, X.stl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]
2026-08-24 added button input, platform system created
2026-08-25 added battery, use wildcard for build script
2026-08-25 pc drivers + abstraction layers finished, starting ui framework
2026-08-26 dumbass readme update oh my god im so tired
2026-08-26 ughhh i think broken button theming? doesnt compile rn
2026-08-28 button themeing works thanks shart gpt
2026-08-30 merged kidna with like uhhh some stuff
    [cheetoPet.kicad_pcb, cheetoPet.kicad_sch]
2026-09-14 pcb v2.1 schematic finished
    [cheetoPet.csv, cheetoPet.kicad_pcb, cheetoPet.kicad_sch]
2026-09-15 pcb tweaks
    [cheetoPet-B_Cu.gbl, cheetoPet-B_Mask.gbs, cheetoPet-B_Paste.gbp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]
2026-09-16 recon mpu
    [cheetoPet.kicad_pcb, cheetoPet.kicad_sch]
2026-09-16 cat lol
    [cheetoPet.kicad_pcb]
2026-09-22 pcb update
2026-09-27 pcb spreadsheet
